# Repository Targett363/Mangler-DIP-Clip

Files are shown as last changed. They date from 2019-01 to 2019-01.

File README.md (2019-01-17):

# Mangler-DIP-Clip
This is a KiCad reworking of @unexpectedmaker SAMD21G-Mangler https://github.com/UnexpectedMaker/SAMD21G-Mangler or https://www.tindie.com/products/seonr/samd21g-mangler/ to add support for a clip style 48pin TQFP to 48pin DIP converter module.

This works for burning the bootloader with an Atmel ICE and programming through the USB however you will notice that I've also broken out pins to use this as a proto board.

I have tested the board for bootloader and usb operation and these work, I had to rework the broken out pins and label them the new version is correct now but untested. I have laveled the pins as in the Arduino M0 board library.

Included files are the KiCad project files and the gerbers needed to make this board.

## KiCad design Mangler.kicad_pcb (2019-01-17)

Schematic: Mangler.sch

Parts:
C1, C2: 10uF; C_1206_3216Metric
C3: 0.1uF; C_0805_2012Metric
C4, C5, C8: 1uF; C_0603_1608Metric
C6, C7: 12.5pF; C_0603_1608Metric
D1: SWDIO; LED_0201_0603Metric
D2: SWCLK; LED_0201_0603Metric
J1: USB; USB_Micro-B_Molex_47346-0001
J2: ICE 10pin; PinSocket_2x05_P1.27mm_Vertical_SMD
J3: ANALOG; PinSocket_1x06_P2.54mm_Vertical
J4: PWR/RESET; PinSocket_1x05_P2.54mm_Vertical
J5: DIGITAL; PinSocket_1x14_P2.54mm_Vertical
J6: I2C; PinSocket_1x04_P2.54mm_Vertical
J7: SPI; PinSocket_1x05_P2.54mm_Vertical
R1, R2: 2.2K; R_0603_1608Metric
U1: TLV1963-33DGYR; SOT-223-3_TabPin2
U2: SAMD21G18A-AF; DIP-48_W16.4mm_Socket
Y1: Crystal; Crystal_SMD_G8-2Pin_3.2x1.5mm

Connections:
+3V3: C2.1, C3.1, C4.1, C5.1, J2.1, J4.1, J4.2, J6.1, J7.1, U1.3 (VO), U2.6, U2.17, U2.36, U2.44
+5V: C1.1, J1.1, U1.1 (VI)
A0: J3.1, U2.3
A1: J3.2, U2.7
A2: J3.3, U2.8
A3: J3.4, U2.9
A4: J3.5, U2.10
A5: J3.6, U2.47
D0: J5.1, U2.16
D1: J5.2, U2.15
D5: J5.6, U2.24
D6: J5.7, U2.29
D9: J5.10, U2.12
D10: J5.11, U2.27
D11: J5.12, U2.25
D12: J5.13, U2.28
D13: J5.14, U2.26
D+: J1.3, U2.34
D-: J1.2, U2.33
GND: C1.2, C2.2, C3.2, C5.2, C6.2, C7.2, C8.2, D1.1, D2.1, J1.5, J1.6, J2.3, J2.5, J4.4, J4.5, J5.3, J5.4, J5.5, J5.8, J5.9, J6.4, J7.5, U1.2 (GND), U2.5, U2.18, U2.35, U2.42
MISO: J7.4, U2.21
MOSI: J7.3, U2.19
unnamed: C4.2, U2.43
unnamed: C6.1, U2.1, Y1.1
unnamed: C7.1, U2.2, Y1.2
unnamed: C8.1, U2.4
unnamed: D1.2, R1.2
unnamed: D2.2, R2.2
RESET: J2.10, J4.3, U2.40
SCK: J7.2, U2.20
SCL: J6.2, U2.32
SDA: J6.3, U2.31
SWCLK: J2.4, R2.1, U2.45
SWDIO: J2.2, R1.1, U2.46

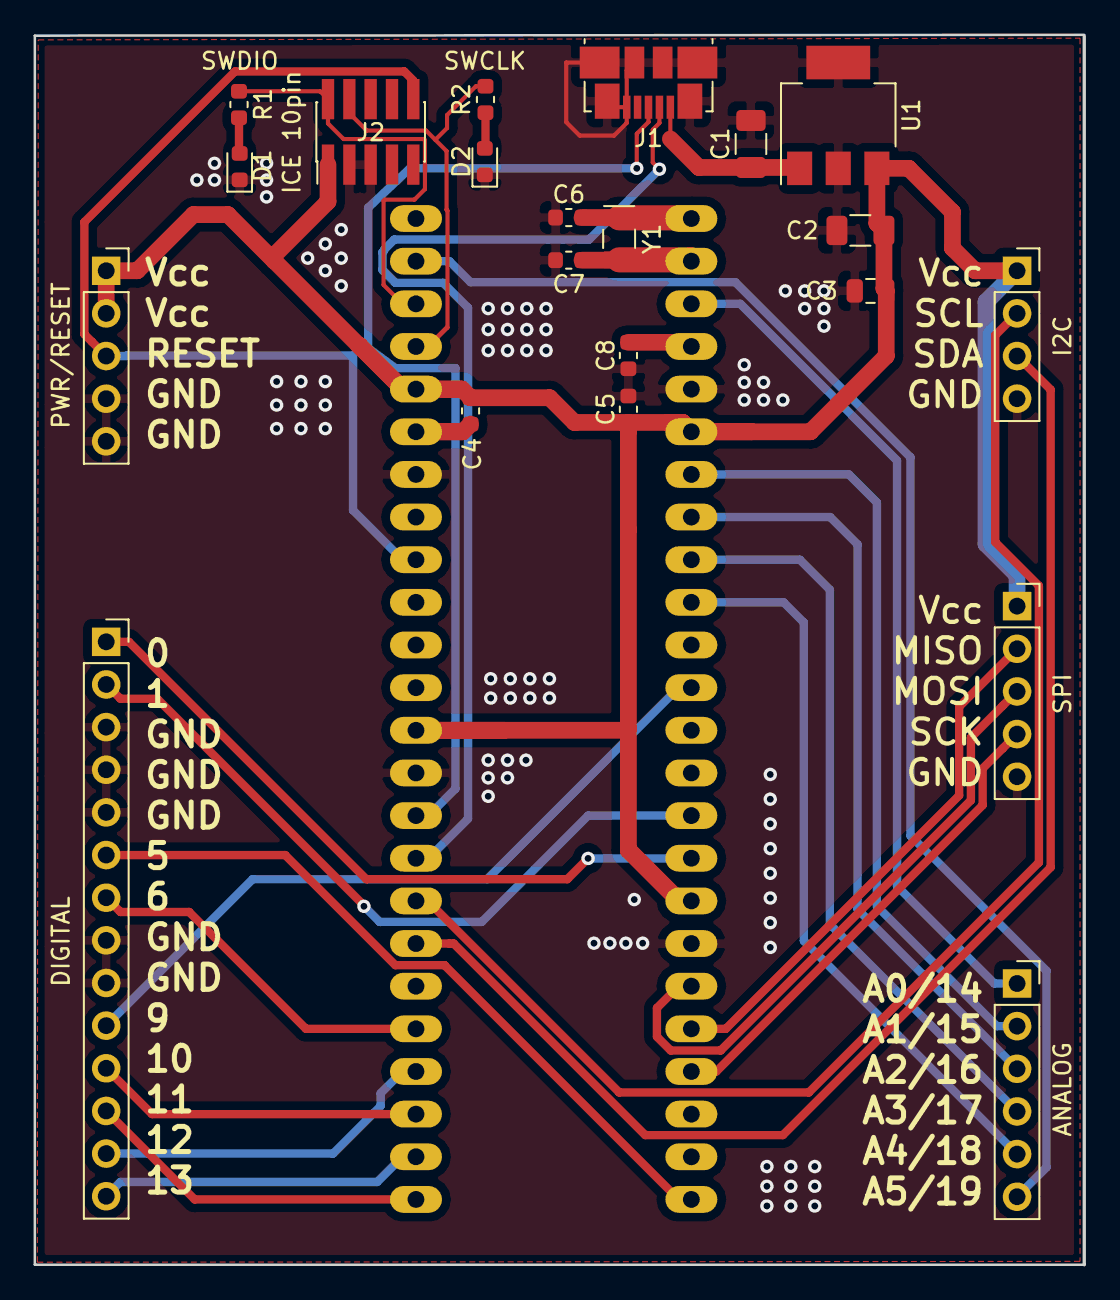
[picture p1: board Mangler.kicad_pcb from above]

Board: 2 copper layers, 62.5 x 73.2 mm, 22 parts (1 on the bottom side), 34 nets.

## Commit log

2019-01-16 This is a KiCad reworking of @unexpectedmaker SAMD21G-Mangler
    https://github.com/UnexpectedMaker/SAMD21G-Mangler or
    https://www.tindie.com/products/seonr/samd21g-mangler/ to add support
    for a clip style chip holder on a 48pin DIP converter module.
    [Mangler-B.Cu.gbr, Mangler-B.Mask.gbr, Mangler-B.Paste.gbr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]
2019-01-17 Pin updates
    Pin location updates and pin labals on silkscreen
    [Mangler.kicad_pcb, Mangler.sch]
2019-01-17 Updated Pins and Gerbers
    [Mangler-B.Cu.gbr, Mangler-B.Mask.gbr, Mangler-B.Paste.gbr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]
